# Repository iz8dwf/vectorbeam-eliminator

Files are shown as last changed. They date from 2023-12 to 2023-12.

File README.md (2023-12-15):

# vectorbeam-eliminator
Digital to analog vector monitor adapter for B&amp;W Vectorbeam/Cinematronics arcade

This board is described and demonstrated in this video:
https://www.youtube.com/watch?v=j_siDBxwS5w

It allows using an "Atari"-compatible arcade analog vector monitor with a CCPU arcade logic board.

It is highly recommended that the circuit initial check is done using an oscilloscope in X-Y mode first,
at least for the offset tuning.

A misbehaving CCPU board can output bad vector data that can damage the vector monitor (and its own digital monitor too)!
Make sure the logic board at least is executing correctly or use an oscilloscope as XY display to stay on the safe side.

USE AT YOUR OWN RISK!

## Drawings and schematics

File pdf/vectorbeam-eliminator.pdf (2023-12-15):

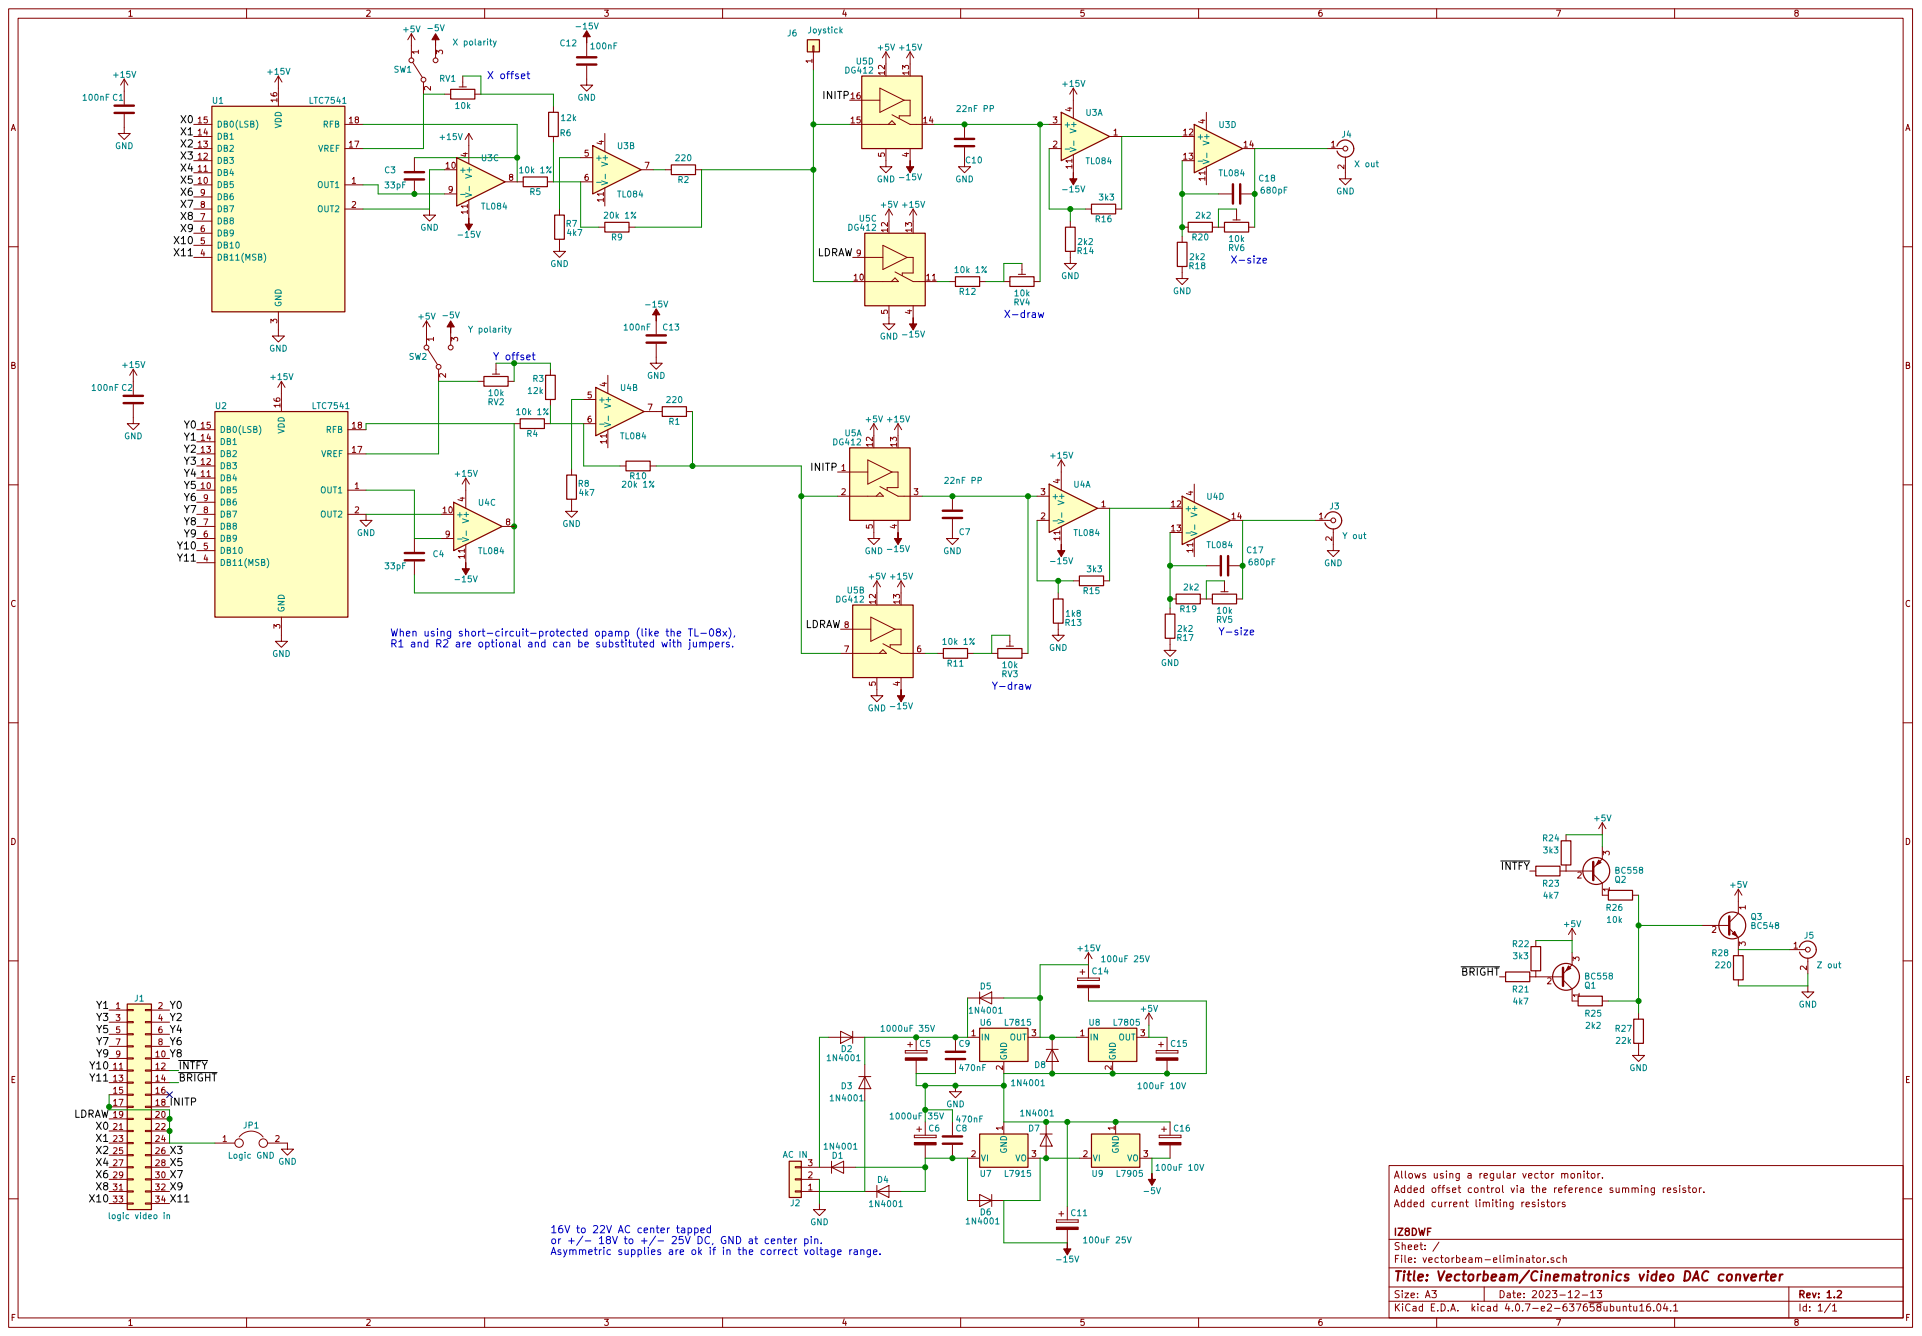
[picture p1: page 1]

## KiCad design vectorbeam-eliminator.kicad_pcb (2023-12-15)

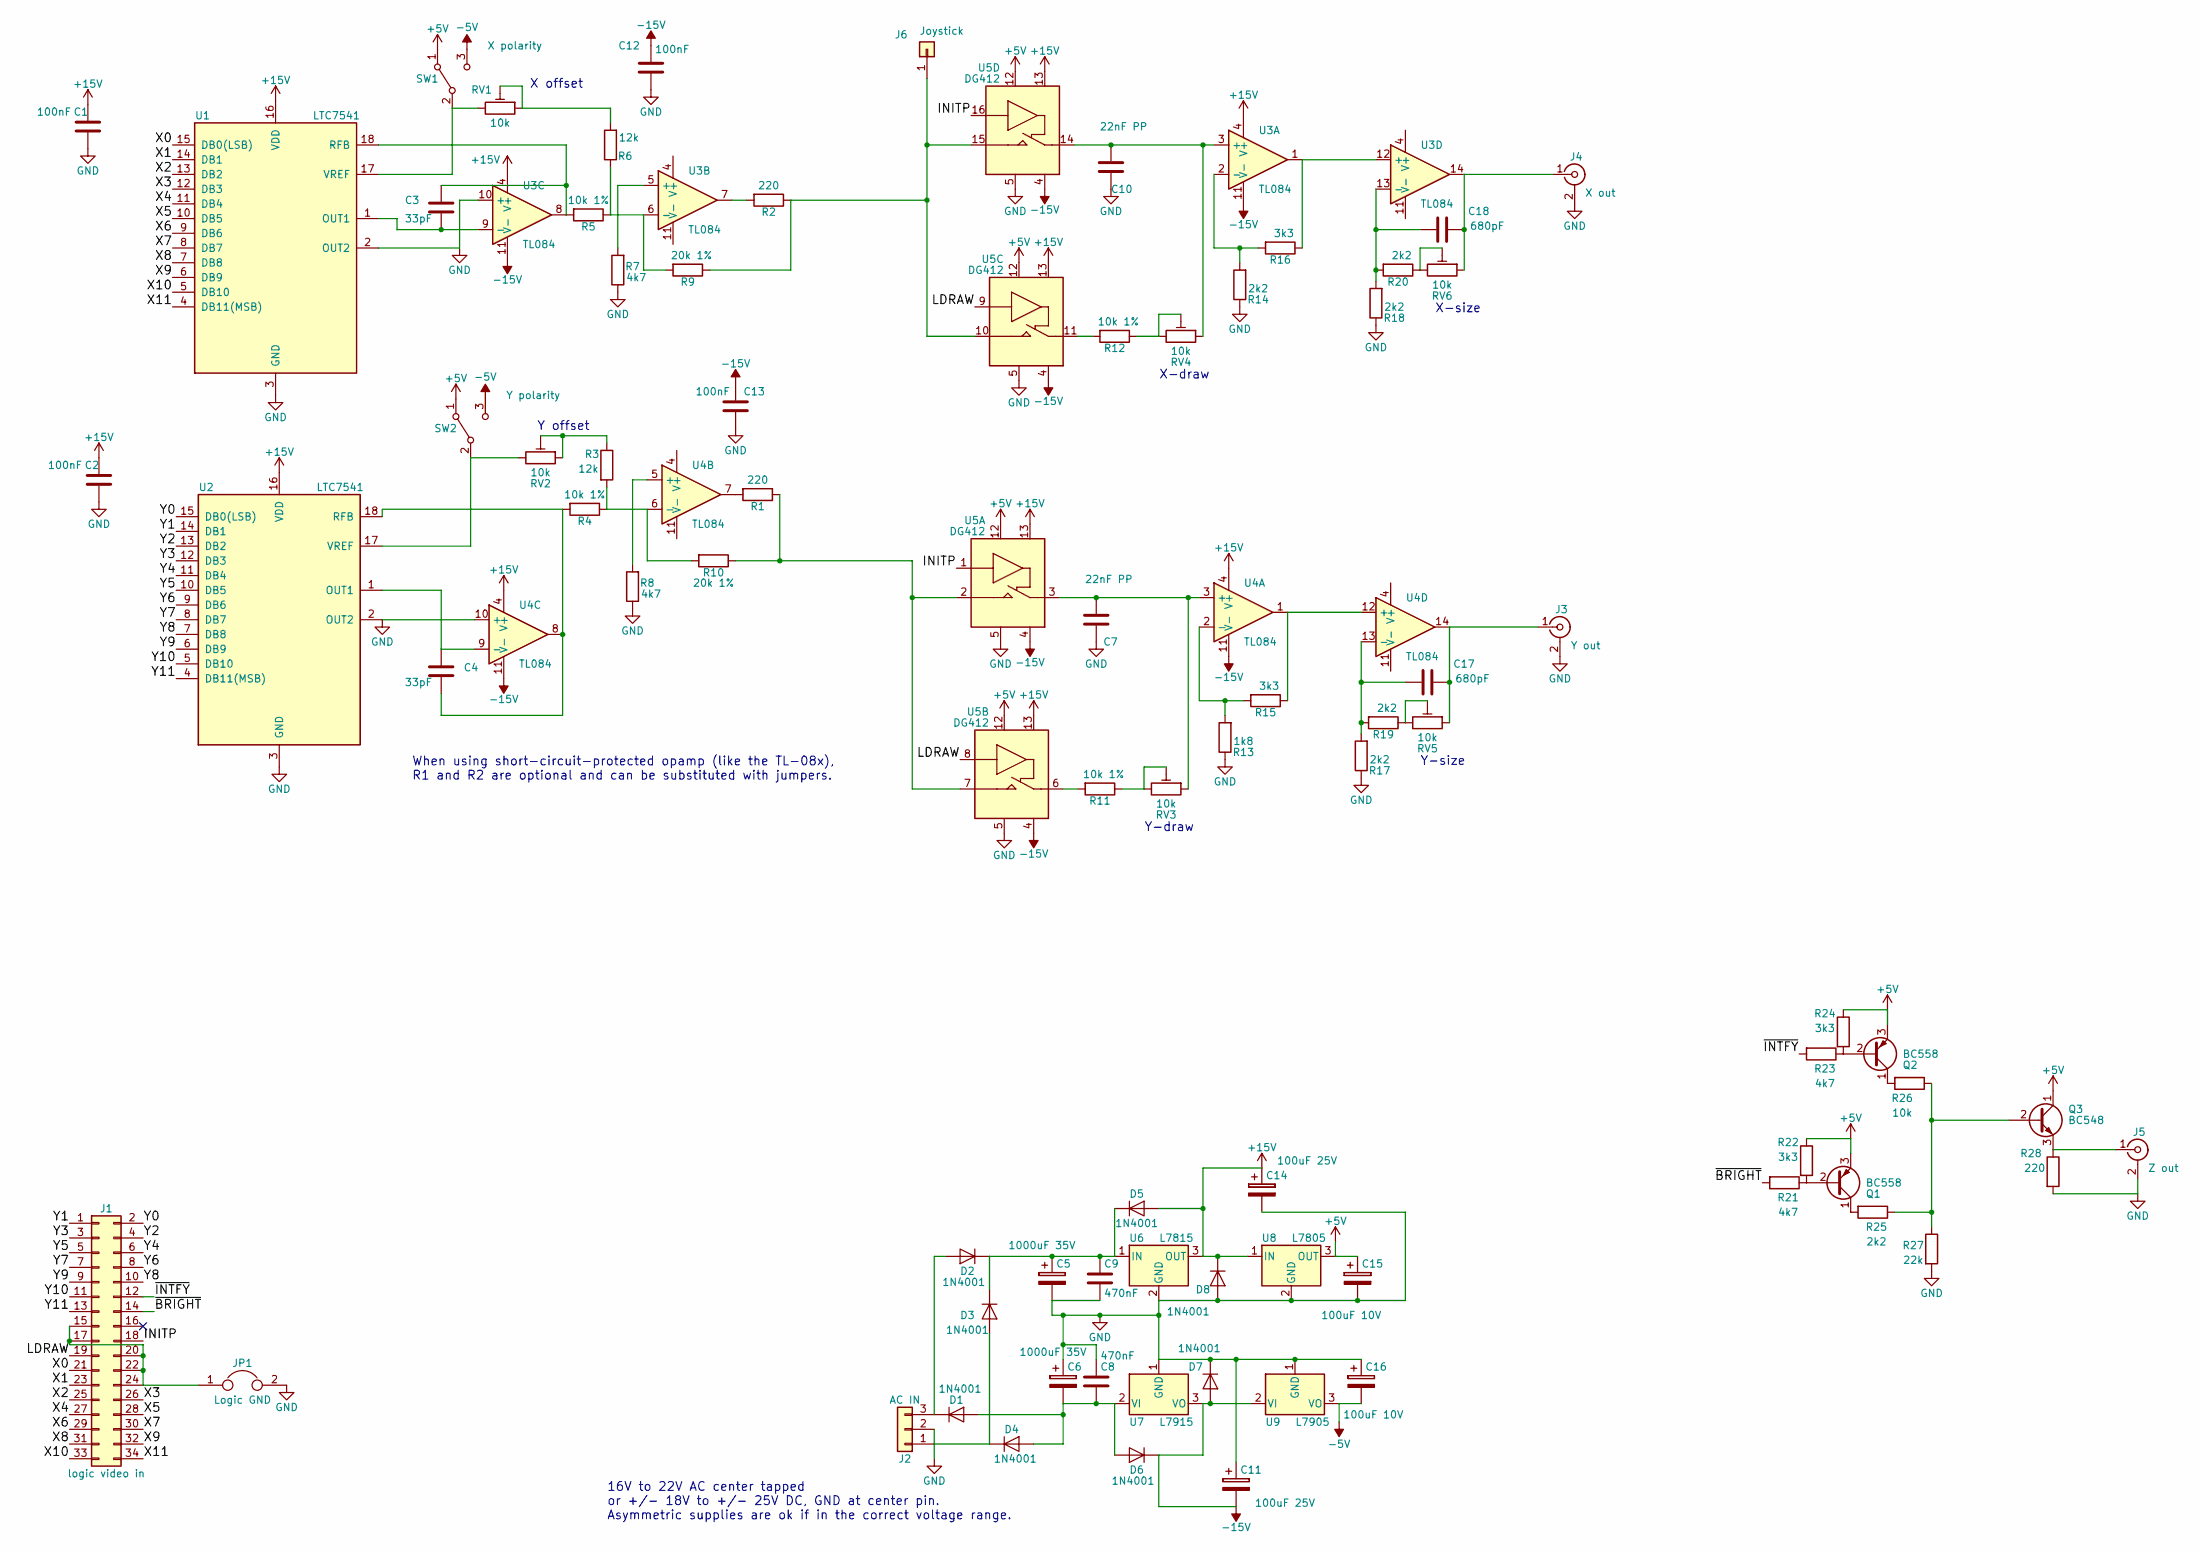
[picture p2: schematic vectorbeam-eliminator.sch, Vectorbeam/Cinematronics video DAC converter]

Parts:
C1, C2, C12, C13: 100nF; C_Rect_L7.2mm_W5.5mm_P5.00mm_FKS2_FKP2_MKS2_MKP2
C3, C4: 33pF; C_Disc_D3.8mm_W2.6mm_P2.50mm
C5, C6: 1000uF 35V; CP_Radial_D12.5mm_P5.00mm
C7, C10: 22nF PP; C_Rect_L7.2mm_W7.2mm_P5.00mm_FKS2_FKP2_MKS2_MKP2
C8, C9: 470nF; C_Rect_L7.2mm_W5.5mm_P5.00mm_FKS2_FKP2_MKS2_MKP2
C11, C14: 100uF 25V; CP_Radial_D8.0mm_P2.50mm
C15, C16: 100uF 10V; CP_Radial_D8.0mm_P2.50mm
C17, C18: 680pF; C_Disc_D3.8mm_W2.6mm_P2.50mm
D1, D2, D3, D4, D5, D6, D7, D8: 1N4001; D_DO-41_SOD81_P10.16mm_Horizontal
J1: logic video in; IDC-Header_2x17_Pitch2.54mm_Straight
J2: AC IN; PINHEAD1-3
J3: Y out; phono_single_angled
J4: X out; phono_single_angled
J5: Z out; phono_single_angled
J6: Joystick; Test_Point_Loop_D2.50mm_Drill1.0mm
JP1: Logic GND; PINHEAD1-2
Q1, Q2: BC558; TO-92_Molded_Narrow
Q3: BC548; TO-92_Molded_Narrow
R1, R2, R28: 220; R_1206_HandSoldering
R3, R6: 12k; R_1206_HandSoldering
R4, R5, R11, R12: 10k 1%; R_1206_HandSoldering
R7, R8, R21, R23: 4k7; R_1206_HandSoldering
R9, R10: 20k 1%; R_1206_HandSoldering
R13: 1k8; R_1206_HandSoldering
R14, R17, R18, R19, R20, R25: 2k2; R_1206_HandSoldering
R15, R16, R22, R24: 3k3; R_1206_HandSoldering
R26: 10k; R_1206_HandSoldering
R27: 22k; R_1206_HandSoldering
RV1, RV2, RV3, RV4, RV5, RV6: 10k; Potentiometer_Trimmer_ACP_CA9v_Horizontal_Px10.0mm_Py5.0mm
SW1: X polarity; Pin_Header_Straight_1x03_Pitch2.54mm
SW2: Y polarity; Pin_Header_Straight_1x03_Pitch2.54mm
U1, U2: LTC7541; DIP-18_W7.62mm_Socket
U3, U4: TL084; DIP-14_W7.62mm_Socket
U5: DG412; SOIC-16_3.9x9.9mm_Pitch1.27mm
U6: L7815; TO-220-3_Vertical
U7: L7915; TO-220-3_Vertical
U8: L7805; TO-220-3_Vertical
U9: L7905; TO-220-3_Vertical

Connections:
+5V: C15.1, Q1.3 (E), Q2.3 (E), Q3.1 (C), R22.1, R24.1, SW1.1 (A), SW2.1 (A), U5.12 (VCC), U8.3 (OUT)
+15V: C1.1, C2.1, C14.1, D5.2 (A), D8.1 (K), U1.16 (VDD), U2.16 (VDD), U3.4 (V+), U4.4 (V+), U5.13 (V+), U6.3 (OUT), U8.1 (IN)
-5V: C16.2, SW1.3 (C), SW2.3 (C), U9.3 (VO)
-15V: C11.2, C12.1, C13.1, D6.1 (K), D7.2 (A), U3.11 (V-), U4.11 (V-), U5.4 (V-), U7.3 (VO), U9.2 (VI)
/INITP: J1.18, U5.1 (SW), U5.16 (SW)
/LDRAW: J1.19, U5.8 (SW), U5.9 (SW)
/X0: J1.21, U1.15 (DB0(LSB))
/X1: J1.23, U1.14 (DB1)
/X2: J1.25, U1.13 (DB2)
/X3: J1.26, U1.12 (DB3)
/X4: J1.27, U1.11 (DB4)
/X5: J1.28, U1.10 (DB5)
/X6: J1.29, U1.9 (DB6)
/X7: J1.30, U1.8 (DB7)
/X8: J1.31, U1.7 (DB8)
/X9: J1.32, U1.6 (DB9)
/X10: J1.33, U1.5 (DB10)
/X11: J1.34, U1.4 (DB11(MSB))
/Y0: J1.2, U2.15 (DB0(LSB))
/Y1: J1.1, U2.14 (DB1)
/Y2: J1.4, U2.13 (DB2)
/Y3: J1.3, U2.12 (DB3)
/Y4: J1.6, U2.11 (DB4)
/Y5: J1.5, U2.10 (DB5)
/Y6: J1.8, U2.9 (DB6)
/Y7: J1.7, U2.8 (DB7)
/Y8: J1.10, U2.7 (DB8)
/Y9: J1.9, U2.6 (DB9)
/Y10: J1.11, U2.5 (DB10)
/Y11: J1.13, U2.4 (DB11(MSB))
/~BRIGHT: J1.14, R21.2
/~INTFY: J1.12, R23.2
GND: C1.2, C2.2, C5.2, C6.1, C7.1, C8.1, C9.2, C10.1, C11.1, C12.2, C13.2, C14.2, C15.2, C16.1, D7.1 (K), D8.2 (A), J2.2, J3.2 (Ext), J4.2 (Ext), J5.2 (Ext), JP1.2, R7.1, R8.1, R13.1, R14.1, R17.1, R18.1, R27.2, R28.2, U1.2 (OUT2), U1.3 (GND), U2.2 (OUT2), U2.3 (GND), U3.10 (+), U4.10 (+), U5.5 (GND), U6.2 (GND), U7.1 (GND), U8.2 (GND), U9.1 (GND)
unnamed: C3.1, R5.2, U1.18 (RFB), U3.8
unnamed: C3.2, U1.1 (OUT1), U3.9 (-)
unnamed: C4.1, U2.1 (OUT1), U4.9 (-)
unnamed: C4.2, R4.2, U2.18 (RFB), U4.8
unnamed: C5.1, C9.1, D2.1 (K), D3.1 (K), D5.1 (K), U6.1 (IN)
unnamed: C6.2, C8.2, D1.2 (A), D4.2 (A), D6.2 (A), U7.2 (VI)
unnamed 39: C7.2, RV3.1, U4.3 (+), U5.3 (OUT); also elsewhere on the board
unnamed 40: C10.2, RV4.1, U3.3 (+), U5.14 (OUT); also elsewhere on the board
unnamed: C17.1, R17.2, R19.2, U4.13 (-)
unnamed 42: C17.2, J3.1 (In), RV5.1, U4.14; also elsewhere on the board
unnamed: C18.1, R18.2, R20.2, U3.13 (-)
unnamed 44: C18.2, J4.1 (In), RV6.1, U3.14; also elsewhere on the board
unnamed: D1.1 (K), D2.2 (A), J2.3
unnamed: D3.2 (A), D4.1 (K), J2.1
unnamed: J1.15, J1.17, J1.20, J1.22, J1.24, JP1.1
unnamed: J5.1 (In), Q3.3 (E), R28.1
unnamed: J6.1, R2.1, R9.1, U5.10 (IN), U5.15 (IN)
unnamed: Q1.1 (C), R25.2
unnamed: Q1.2 (B), R21.1, R22.2
unnamed: Q2.1 (C), R26.2
unnamed: Q2.2 (B), R23.1, R24.2
unnamed: Q3.2 (B), R25.1, R26.1, R27.1
unnamed: R1.1, R10.1, U5.2 (IN), U5.7 (IN)
unnamed: R1.2, U4.7
unnamed: R2.2, U3.7
unnamed 59: R3.1, RV2.1, RV2.2; also elsewhere on the board
unnamed: R5.1, R6.1, R9.2, U3.6 (-)
unnamed 61: R6.2, RV1.1, RV1.2; also elsewhere on the board
unnamed: R7.2, U3.5 (+)
unnamed: R8.2, U4.5 (+)
unnamed: R3.2, R4.1, R10.2, U4.6 (-)
unnamed 65: R11.1, RV3.2, RV3.3; also elsewhere on the board
unnamed: R11.2, U5.6 (OUT)
unnamed 67: R12.1, RV4.2, RV4.3; also elsewhere on the board
unnamed: R12.2, U5.11 (OUT)
unnamed: R13.2, R15.2, U4.2 (-)
unnamed: R14.2, R16.2, U3.2 (-)
unnamed: R15.1, U4.1, U4.12 (+)
unnamed: R16.1, U3.1, U3.12 (+)
unnamed 73: R19.1, RV5.2, RV5.3; also elsewhere on the board
unnamed 74: R20.1, RV6.2, RV6.3; also elsewhere on the board
unnamed 75: RV1.3, SW1.2 (B), U1.17 (VREF); also elsewhere on the board
unnamed 76: RV2.3, SW2.2 (B), U2.17 (VREF); also elsewhere on the board

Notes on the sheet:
X-draw
X-size
Y-draw
Y-size
X offset
Y offset
When using short-circuit-protected opamp (like the TL-08x), R1 and R2 are optional and can be substituted with jumpers.
16V to 22V AC center tapped or +/- 18V to +/- 25V DC, GND at center pin. Asymmetric supplies are ok if in the correct voltage range.

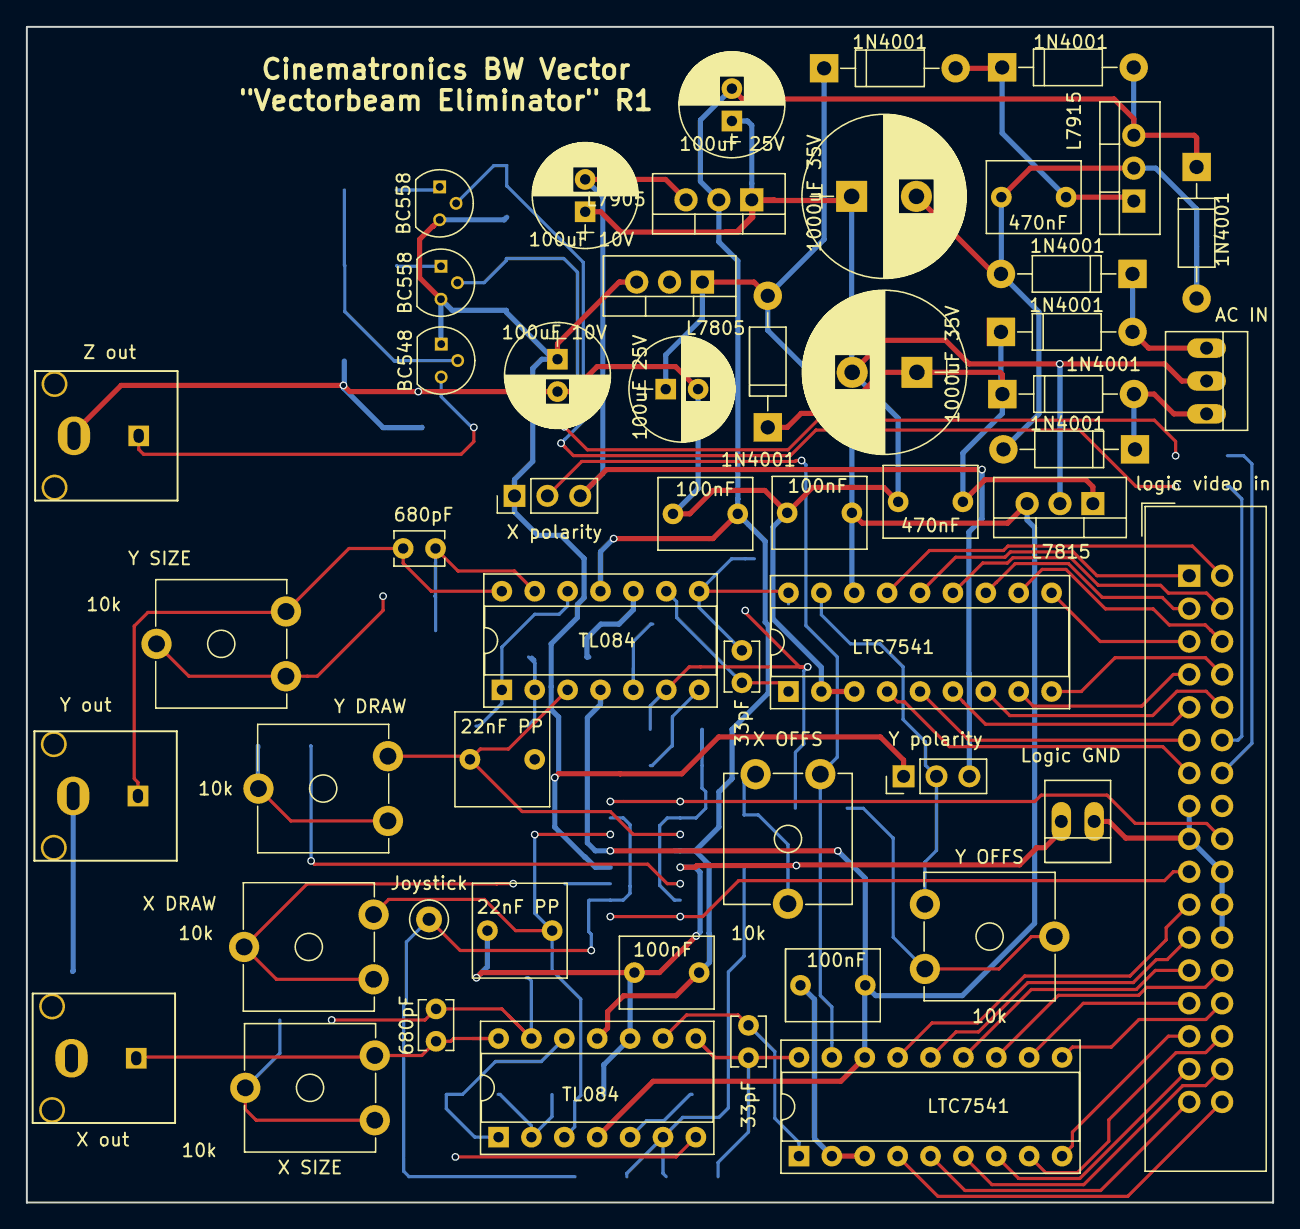
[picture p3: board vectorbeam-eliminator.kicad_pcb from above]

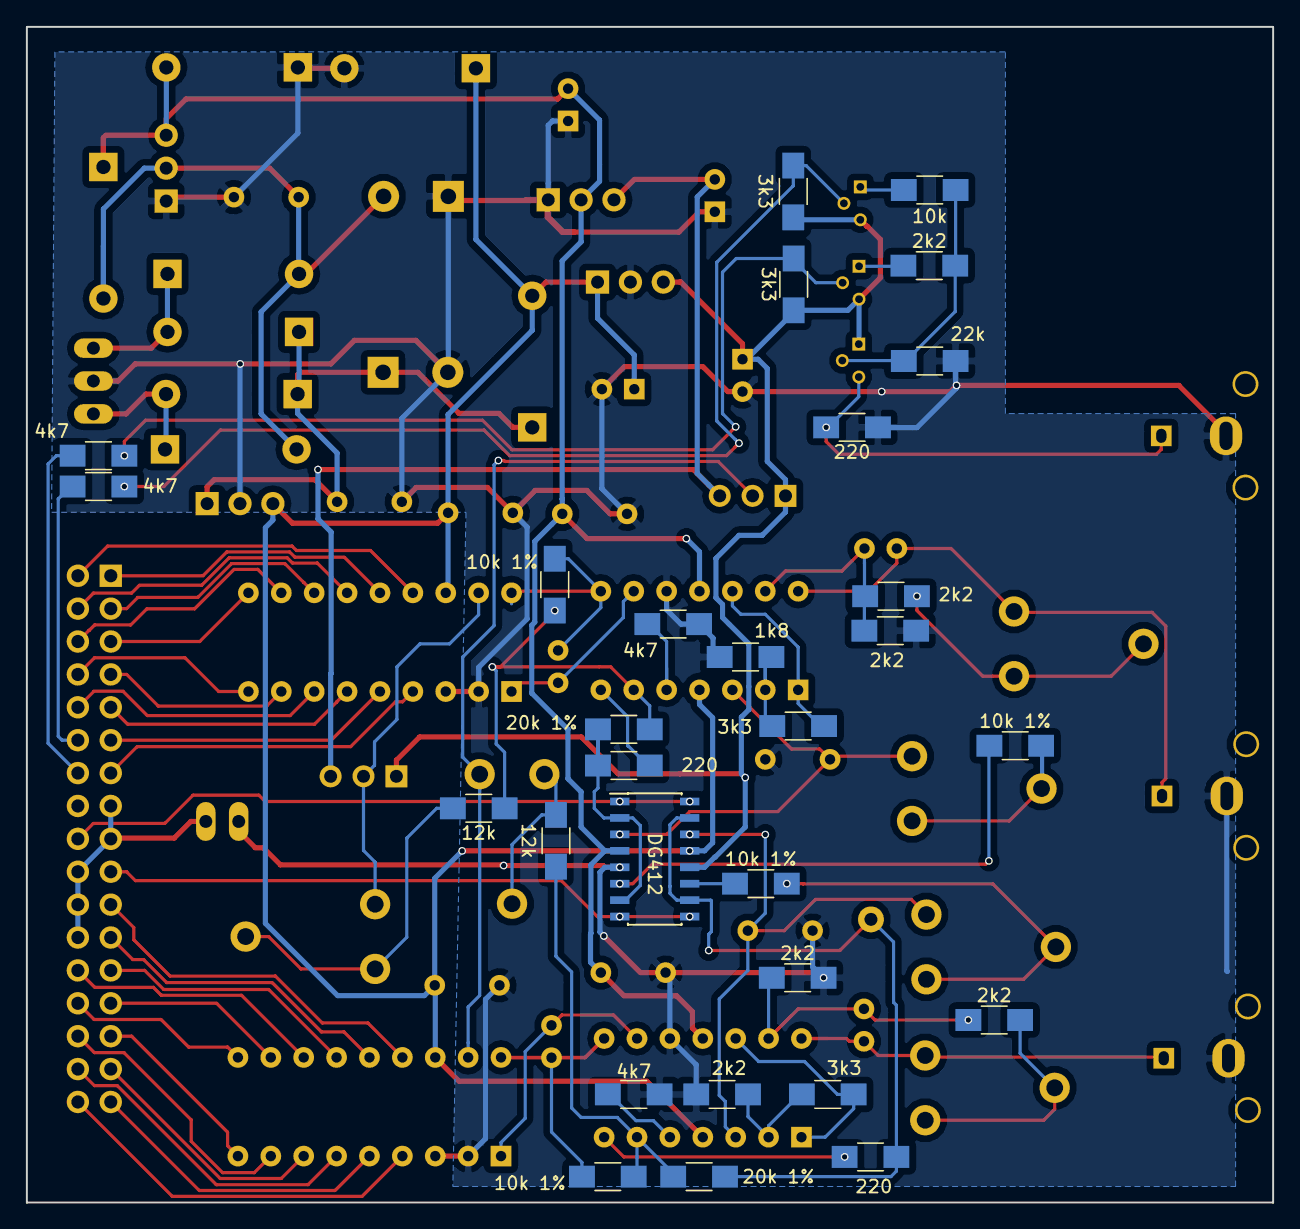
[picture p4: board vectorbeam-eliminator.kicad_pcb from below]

Board: 2 copper layers, 96.2 x 90.8 mm, 81 parts (29 on the bottom side), 76 nets.

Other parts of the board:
X DRAW: 10k; Potentiometer_Trimmer_ACP_CA9v_Horizontal_Px10.0mm_Py5.0mm
X OFFS: 10k; Potentiometer_Trimmer_ACP_CA9v_Horizontal_Px10.0mm_Py5.0mm
X SIZE: 10k; Potentiometer_Trimmer_ACP_CA9v_Horizontal_Px10.0mm_Py5.0mm
Y DRAW: 10k; Potentiometer_Trimmer_ACP_CA9v_Horizontal_Px10.0mm_Py5.0mm
Y OFFS: 10k; Potentiometer_Trimmer_ACP_CA9v_Horizontal_Px10.0mm_Py5.0mm
Y SIZE: 10k; Potentiometer_Trimmer_ACP_CA9v_Horizontal_Px10.0mm_Py5.0mm

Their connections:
unnamed 39: Y DRAW.1; also elsewhere on the board
unnamed 40: X DRAW.1; also elsewhere on the board
unnamed 42: Y SIZE.1; also elsewhere on the board
unnamed 44: X SIZE.1; also elsewhere on the board
unnamed 59: Y OFFS.1, Y OFFS.2; also elsewhere on the board
unnamed 61: X OFFS.1, X OFFS.2; also elsewhere on the board
unnamed 65: Y DRAW.2, Y DRAW.3; also elsewhere on the board
unnamed 67: X DRAW.2, X DRAW.3; also elsewhere on the board
unnamed 73: Y SIZE.2, Y SIZE.3; also elsewhere on the board
unnamed 74: X SIZE.2, X SIZE.3; also elsewhere on the board
unnamed 75: X OFFS.3; also elsewhere on the board
unnamed 76: Y OFFS.3; also elsewhere on the board
